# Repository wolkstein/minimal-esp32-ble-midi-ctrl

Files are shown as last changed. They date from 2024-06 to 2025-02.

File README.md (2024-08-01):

# Minimal ESP32 BLE Midi Control Interface

This project is a minimal ESP32 BLE MIDI controller. It allows you to control MIDI devices wirelessly using Bluetooth Low Energy (BLE) technology. The controller is designed to be compact and easy to use, making it ideal for musicians and performers.

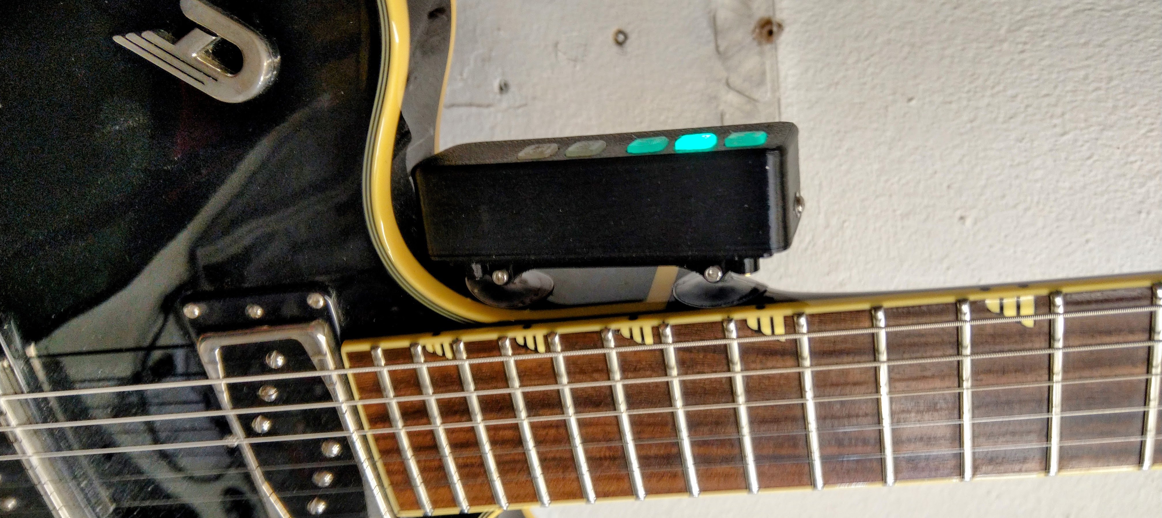
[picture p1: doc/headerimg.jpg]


## Features

- BLE MIDI connectivity
- Compact and portable design
- Easy-to-use interface
- Easy-to-use Web UI to make settings
- Online Firmware Update
- With Ardour and Harrison Mixbus compatible midi_map file
- as Platformio Project (esp32 arduino framework)

## Parts
- ESP32-S3-Mini
- 5 momentary button switches
- 5 10k resistors
- breadboard
- optional rgb led ws28xx

## PCB Version with Lipo and Battery Charger

PCB:

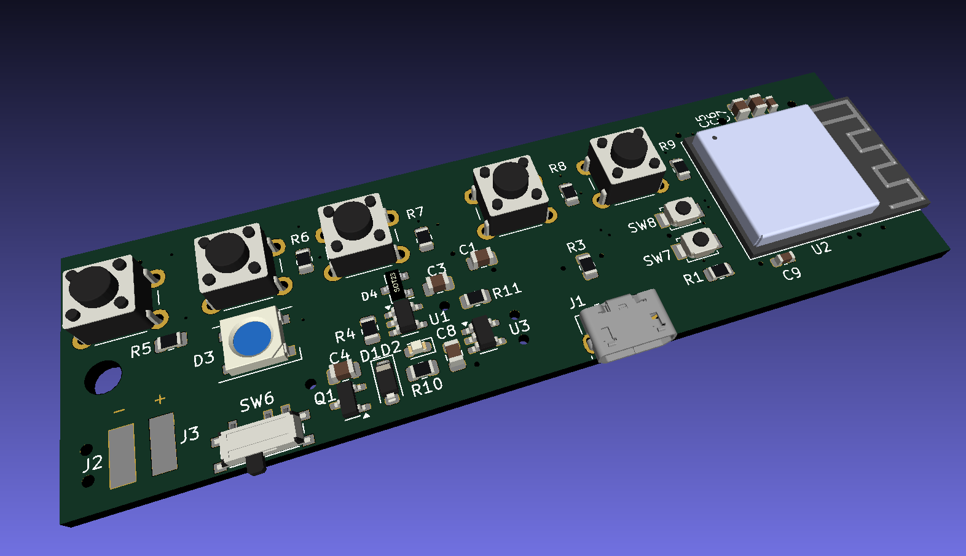
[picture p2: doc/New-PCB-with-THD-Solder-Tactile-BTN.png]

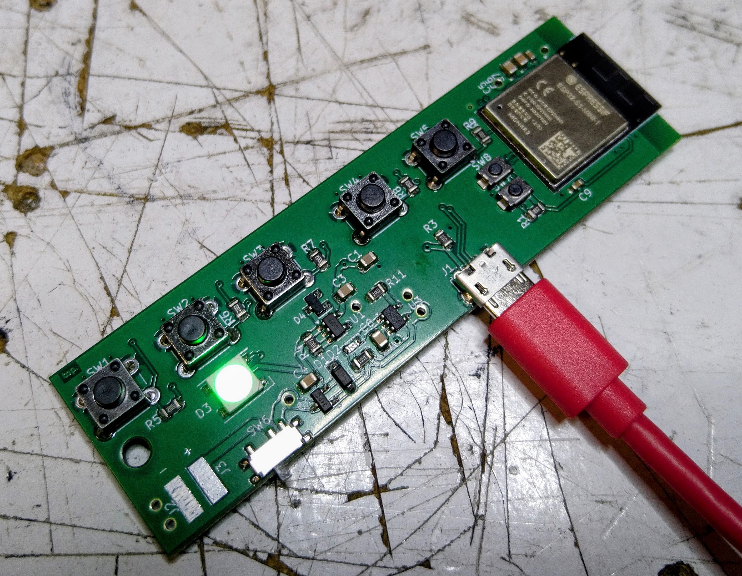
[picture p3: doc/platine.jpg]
PCB - finished


Housing:
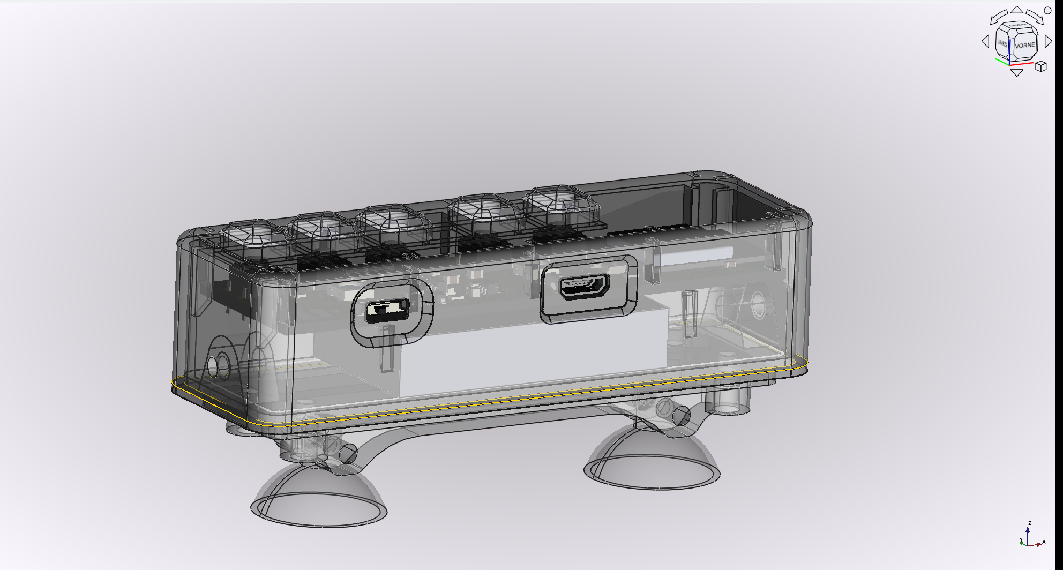
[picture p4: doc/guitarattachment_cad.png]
Housing


## Getting Started

To get started with the project, follow these steps:

1. Clone the repository: `$ git clone https://github.com/wolkstein/minimal-esp32-ble-midi-ctrl`
2. Open as Platformio Project for example with VSC Pio Extension
3. Connect your ESP32 device to your computer via USB.
4. Change the platformio.ini as you need
5. Press PIO upload button
6. Your ESP32 BLE MIDI controller is now ready to use!

## Contributing

Contributions are welcome! If you have any ideas, suggestions, or bug reports, please open an issue or submit a pull request.

## License

This project is licensed under the GNU General Public License v3.0. See the [LICENSE](LICENSE) file for more information.

## Linux howto BlueZ with MIDI over BLE Support

Nice Howto from Peter P:

https://tttapa.github.io/Pages/Ubuntu/Software-Installation/BlueZ.html

After compiling BlueZ, Little Helper shown in Catja App

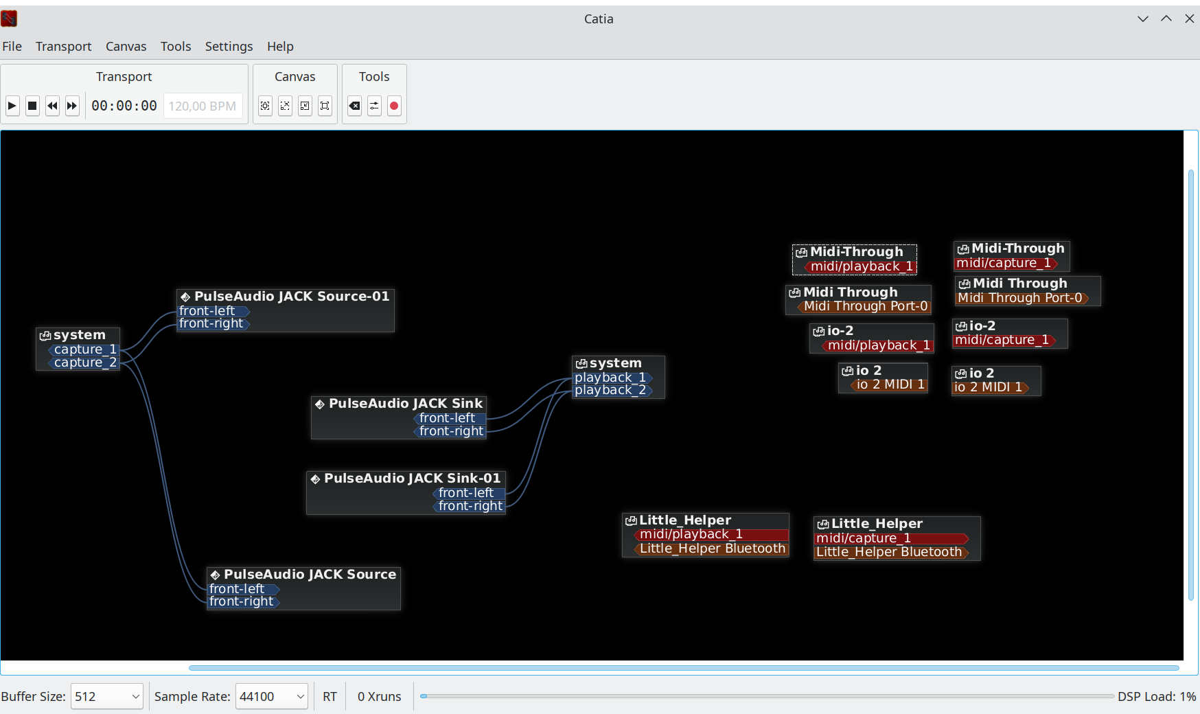
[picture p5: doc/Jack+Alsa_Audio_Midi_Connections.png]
Catja on Ubuntu 22.04


## Ardour / Mixbus Midi Setup

- For example copy the Midi Map file from this Repo like this:
```bash
cp DAW_MIDI_MAPS/ArdourAndHarrisonMixbus/midi_mapsLittle_Helper.map ~/.config/ardour6/midi_maps
```
- Now you can open the Edit-Preferences Window in Ardour, and under Control Surfaces, select Generic Midi
- Press Show Protocol Settings
- Now you can select "Little_Helper" in Midi Bindings dropdown
- if Little Helper is already connected via bluetooth you can make connection in Incoming Midi Dropdown like in the Image below
- Done  

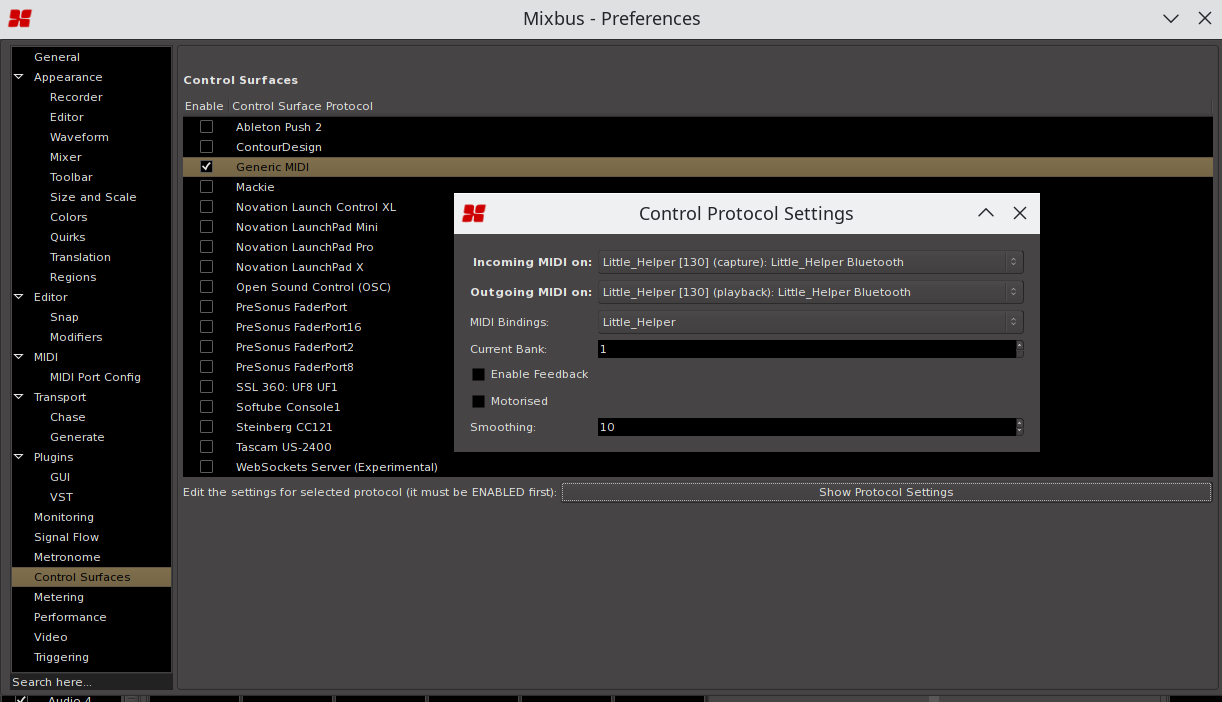
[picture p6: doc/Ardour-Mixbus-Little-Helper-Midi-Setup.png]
Ardour Mixbus Midi


---
## Some more pictures of how it is used

### All parts

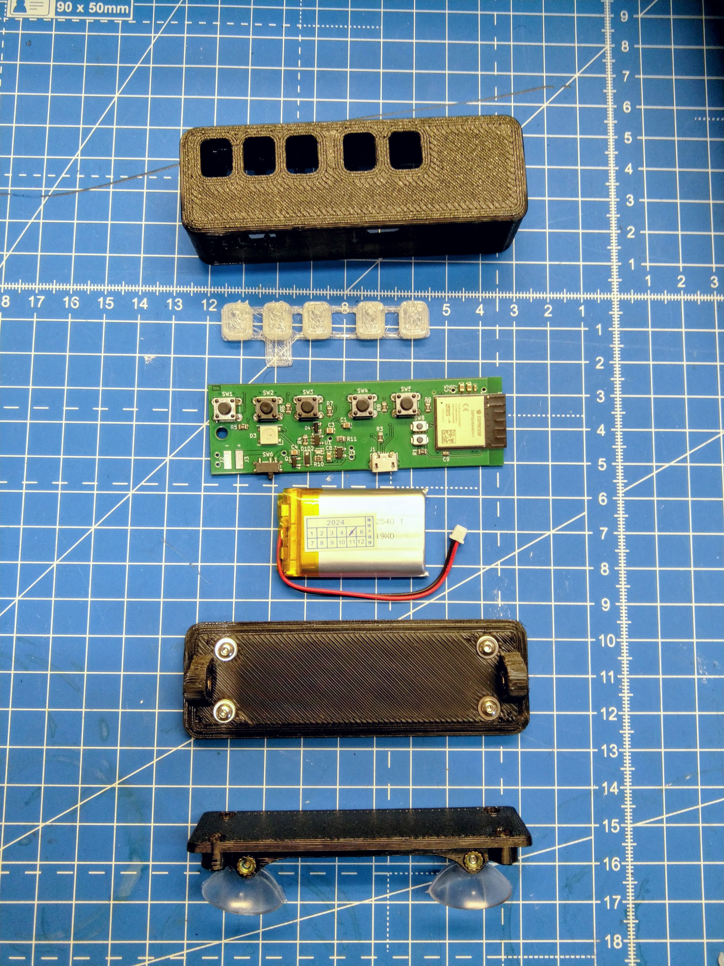
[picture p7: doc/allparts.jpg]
All Parts


### Guitar attachment

Guitar attachment cad
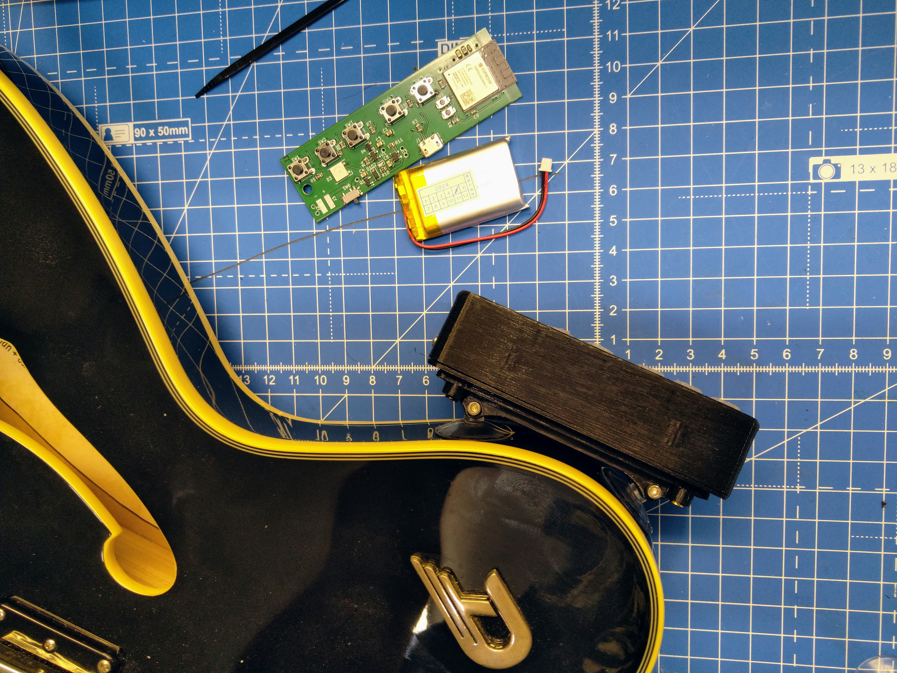
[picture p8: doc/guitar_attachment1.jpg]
Guitar attachment

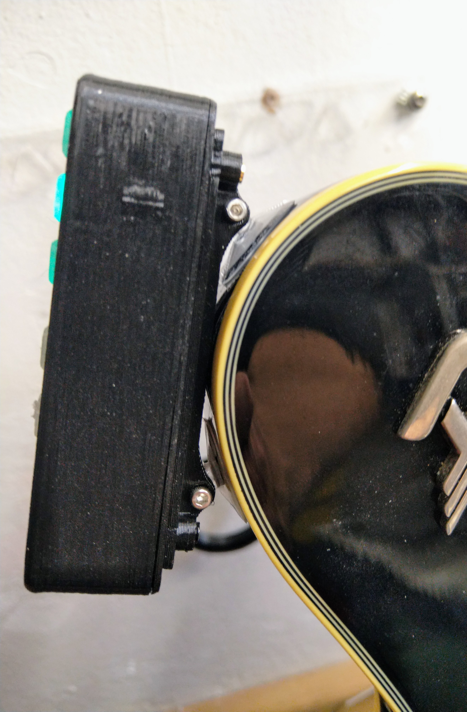
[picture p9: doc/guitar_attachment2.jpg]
Guitar attachment

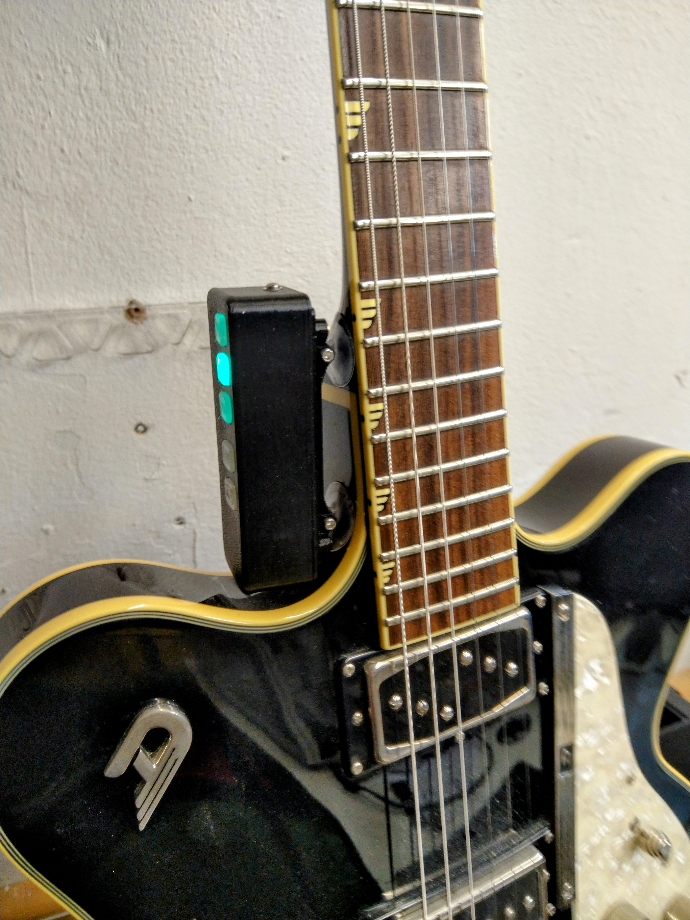
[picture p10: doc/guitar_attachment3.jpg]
Guitar attachment


### Web interface

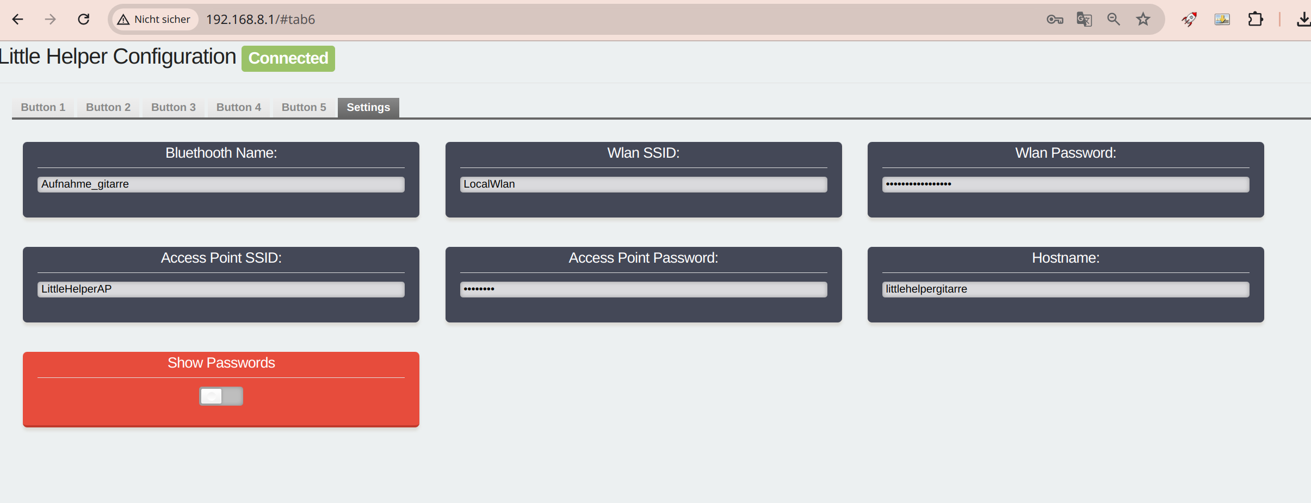
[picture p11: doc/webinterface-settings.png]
Settings

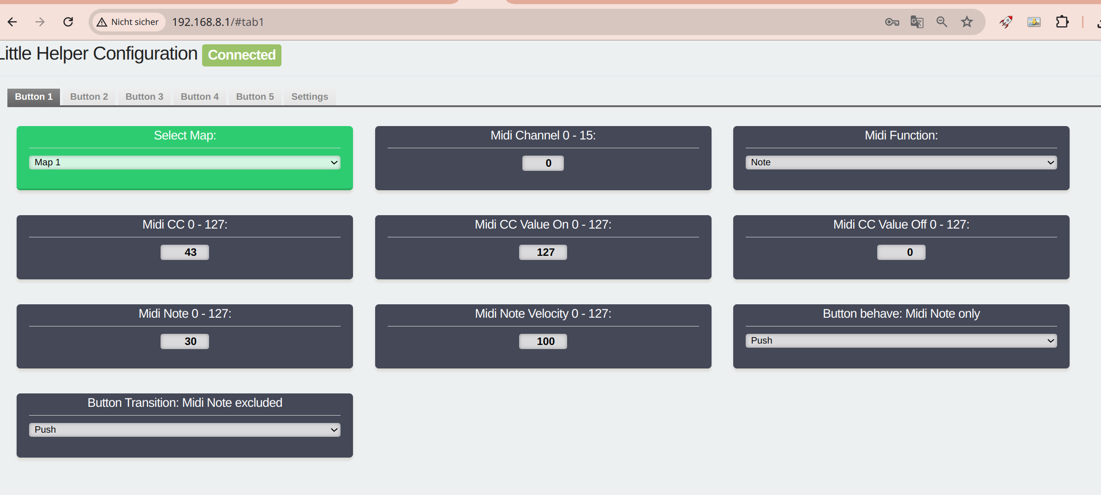
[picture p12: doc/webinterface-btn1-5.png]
Btn Tabs 1 - 5


---
## Simple Manual

### First Wi-Fi Connection and Settings

#### To connect to the built-in access point, follow these steps:

1. Power on your ESP32 BLE MIDI controller while pressing Btn 4 and 5
2. Wait til LED becomes Blue
3. Once initialized, the controller will start broadcasting its own access point (AP) named "LittleHelperAP-xxx"
4. On your computer or mobile device, go to the Wi-Fi settings and connect to the "LittleHelperAP-xxx" network.
5. Open a web browser and enter the following URL: `http://192.168.8.1`.
6. You will be redirected to the controller's web interface.
7. In the web interface, navigate to the "Settings" Tab.

After completing the initial steps, the device is now capable of connecting to a local network. If the user desires, they can hold down buttons 4 and 5 while powering down the device. This will allow the device to connect to a local Wi-Fi network and start the web UI for making MIDI settings, if necessary.

## Firmware Update over WiFi Connection

To update the firmware of your ESP32 BLE MIDI controller over a WiFi connection, follow these steps:

1. Ensure that your ESP32 BLE MIDI controller is connected to your local WiFi network. You can do this by navigating to the "Settings" tab in the controller's web interface and entering your WiFi credentials.

2. Once connected, go to the Settings Tab and check the label that displays the current firmware version (e.g., s3miniVx).

3. Visit the GitHub project page for Little Helper and go to the "Binary" folder (https://github.com/wolkstein/minimal-esp32-ble-midi-ctrl/tree/main/bin) to check if there is a newer firmware available. Look for a firmware version number that is higher than the one displayed in the firmware label.

4. If a newer firmware is available, you can proceed with the update.

5. In the Settings Tab, click the "Try Update" button to request the firmware update.

6. After clicking the button, you will see a message saying "Update Requested, need Reboot".

7. Turn off the power to your ESP32 BLE MIDI controller by switching the power switch to the "off" position and removing the USB cable.

8. Power on the device again either by switching the power switch back on or by connecting the USB cable.

9. Wait for the LED on the device to turn yellow. This indicates that the device is in update mode and is connected to your local network.

10. If the LED starts blinking purple, it means that the update process is running. Wait until the LED switches back to its normal red or green light. If the LED does not blink purple, it means that the device has rebooted without performing the update.

11. If the update fails, you can simply try again. If something goes wrong during the update, the previous firmware will be automatically recovered.

12. If the update is successful, you can reconnect to the web interface and check the firmware version label to confirm the update.

---
# Button Combinations at Power up

This section describes the button combinations and their corresponding functions that can be used during power up.
Btn 1 to btn 5 from left to right.

| Button Combination | Function |
| --- | --- |
| o o o x x | Connect To Local Wifi Network and enable Web UI |
| o o x x x | Start AP Mode and enable Web UI |
| x x o o o | Reset Midi Settings to Default |
| x o x o o | Reset Midi Settings and Wifi Settings to Default |

x = pressed,
o = released

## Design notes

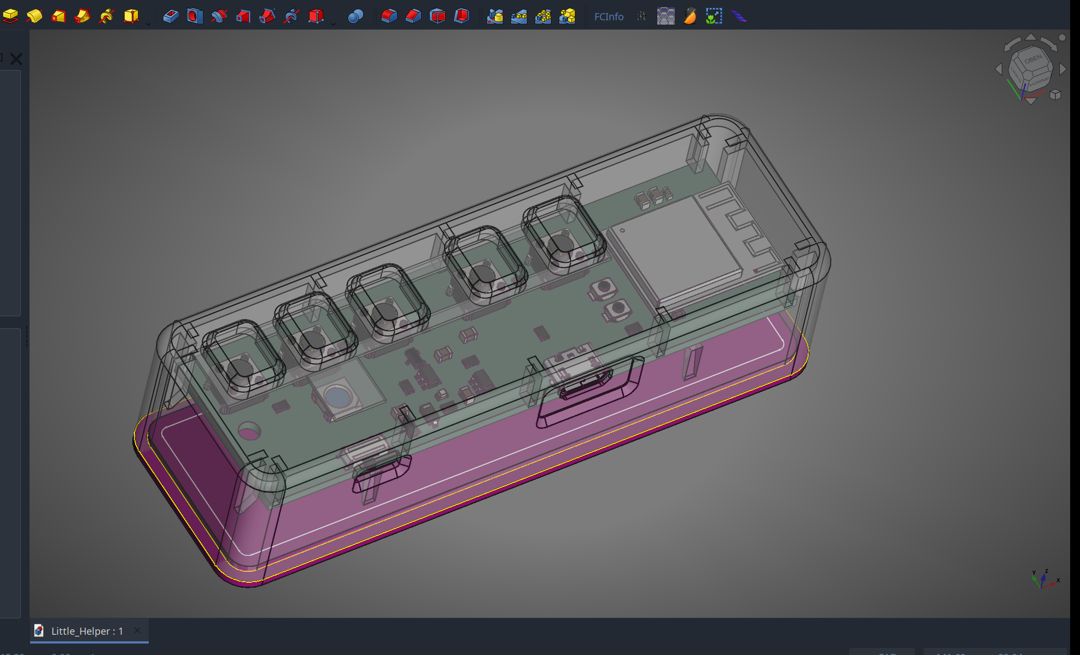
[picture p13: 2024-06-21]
doc/Freecad-Housing.png

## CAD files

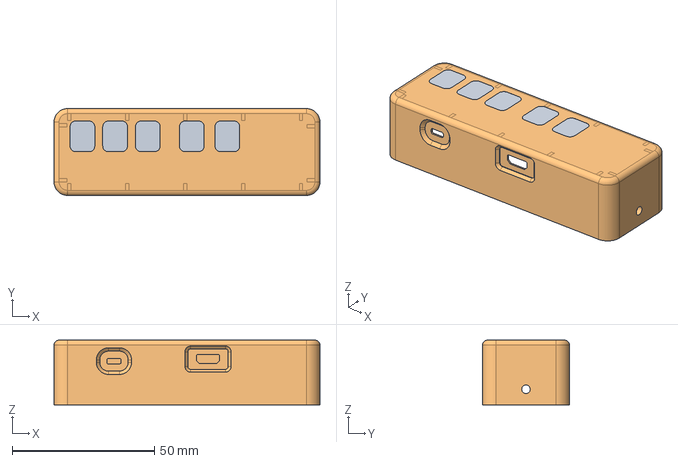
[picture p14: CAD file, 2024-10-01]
Hardware/FreeCadProject/Little_Helper.FCStd
93.6 x 30.6 x 22.8 mm
Housing

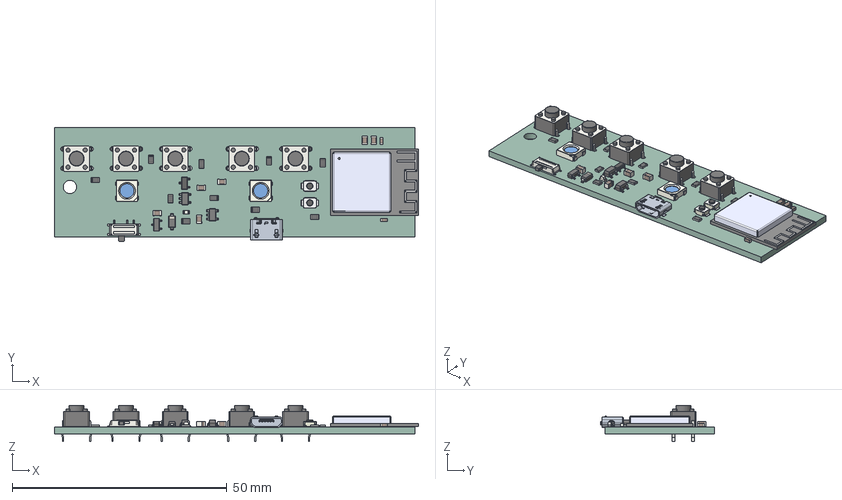
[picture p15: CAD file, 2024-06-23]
Hardware/KicadProject/Little_Helper/Little_Helper.step
84.8 x 26.7 x 8.50 mm
ESP32-S3-MINI-1-N8
LED_0603_1608Metric
R_0805_2012Metric x 10
C_0805_2012Metric x 6
SW_SPST_B3U-1000P x 2
SW_PUSH_6mm_h5mm x 5
C_0603_1608Metric x 2
LED_WS2812B_PLCC4_50x50mm_P32mm x 2
SOT_23
Pad_(Mirror_#2)
Fusion_sp
SOT_23_5 x 2
D_SOD_123
Little_Helper_PCB

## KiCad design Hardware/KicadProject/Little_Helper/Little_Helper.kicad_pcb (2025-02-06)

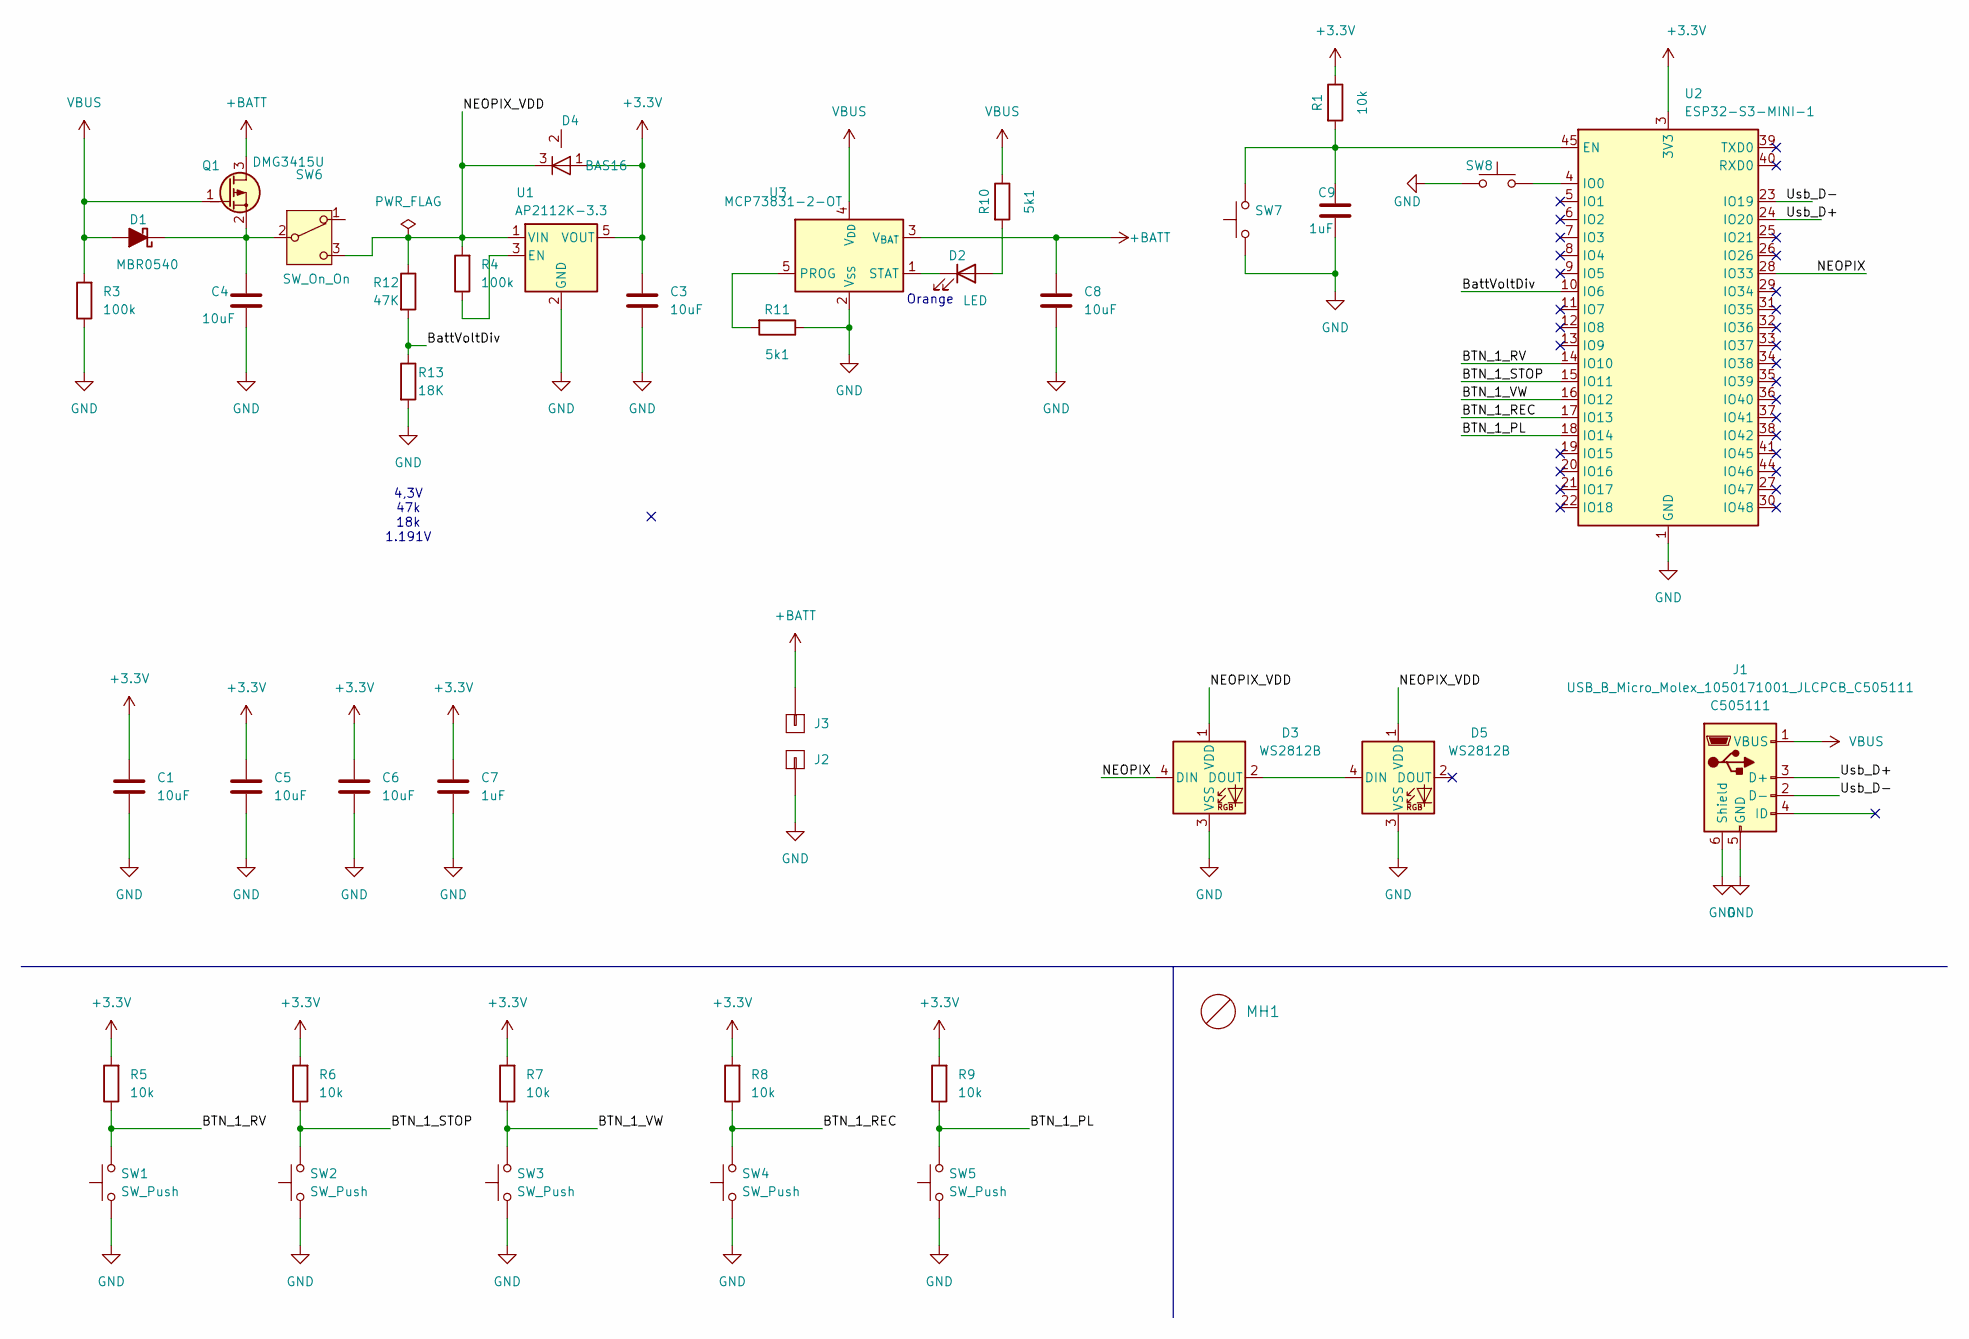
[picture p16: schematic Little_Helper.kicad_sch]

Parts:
C1, C3, C4, C5, C6, C8: 10uF; C_0805_2012Metric; LCSC C1713
C7, C9: 1uF; C_0603_1608Metric; LCSC C1592
D1: MBR0540; D_SOD-123; LCSC C78545
D2: LED; LED_0603_1608Metric; LCSC C2286
D3, D5: WS2812B; LED_WS2812B_JLCPCB_5.0x5.0mm_P3.2mm; LCSC C2843785
D4: BAS16; sot_23; MPN BAS16,215; LCSC C79997
J1: USB_B_Micro_Molex_1050171001_JLCPCB_C505111; USB_Micro-B_Molex-105017-0001; MPN 1050171001; LCSC Part # C505111
J2, J3: SOLDER_CON_5x2_TOP; solder_con_5x2_top
MH1: fit_3_1
Q1: DMG3415U; SOT-23; LCSC C96616
R1, R5, R6, R7, R8, R9: 10k; R_0805_2012Metric; LCSC C17414
R3, R4: 100k; R_0805_2012Metric; LCSC C149504
R10, R11: 5k1; R_0805_2012Metric; LCSC C115316
R12: 47K; r2012; LCSC Part # C17713
R13: 18K; r2012; LCSC Part # C17506
SW1, SW2, SW3, SW4, SW5: SW_Push; SW_PUSH_6mm_H5mm
SW6: SW_On_On; SW_SPDT_PCM12; MPN MK-12C02-G020; LCSC Part # C963206
SW7, SW8: SW_Tactile_Small; SW_SPST_TS-1088-AR02016; MPN TS-1088-AR02016; LCSC Part # C720477
U1: AP2112K-3.3; SOT-23-5; LCSC C51118
U2: ESP32-S3-MINI-1; ESP32-S2-MINI-1; LCSC C2913206
U3: MCP73831-2-OT; SOT-23-5; LCSC C424093

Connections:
+3.3V: C1.1, C3.1, C5.1, C6.1, C7.1, D4.1 (A), R1.1, R5.2, R6.2, R7.2, R8.2, R9.2, U1.5 (VOUT), U2.3 (3V3)
+BATT: C8.1, J3.1, Q1.3 (D), U3.3 (V_{BAT})
/BTN_1_PL: R9.1, SW5.2, U2.18 (IO14)
/BTN_1_REC: R8.1, SW4.2, U2.17 (IO13)
/BTN_1_RV: R5.1, SW1.2, U2.14 (IO10)
/BTN_1_STOP: R6.1, SW2.2, U2.15 (IO11)
/BTN_1_VW: R7.1, SW3.2, U2.16 (IO12)
/BattVoltDiv: R12.2, R13.1, U2.10 (IO6)
/NEOPIX: D3.4 (DIN), U2.28 (IO33)
/NEOPIX_VDD: D3.1 (VDD), D4.3 (K), D5.1 (VDD), R4.2, R12.1, SW6.3 (C), U1.1 (VIN)
/Usb_D+: J1.3 (D+), U2.24 (IO20)
/Usb_D-: J1.2 (D-), U2.23 (IO19)
GND: C1.2, C3.2, C4.2, C5.2, C6.2, C7.2, C8.2, C9.2, D3.3 (VSS), D5.3 (VSS), J1.5 (GND), J1.6 (Shield), J2.1, R3.1, R11.1, R13.2, SW1.1, SW2.1, SW3.1, SW4.1, SW5.1, SW7.1 (A), SW8.1 (A), U1.2 (GND), U2.1 (GND), U2.2 (GND), U2.42 (GND), U2.43 (GND), U2.46 (GND), U2.47 (GND), U2.48 (GND), U2.49 (GND), U2.50 (GND), U2.51 (GND), U2.52 (GND), U2.53 (GND), U2.54 (GND), U2.55 (GND), U2.56 (GND), U2.57 (GND), U2.58 (GND), U2.59 (GND), U2.60 (GND), U2.61 (GND), U2.62 (GND), U2.63 (GND), U2.64 (GND), U2.65 (GND), U3.2 (V_{SS})
unnamed: C4.1, D1.1 (K), Q1.2 (S), SW6.2 (B)
unnamed: D2.2 (A), R10.2
unnamed: D2.1 (K), U3.1 (STAT)
unnamed: D3.2 (DOUT), D5.4 (DIN)
unnamed: R4.1, U1.3 (EN)
unnamed: C9.1, R1.2, SW7.2 (A), U2.45 (EN)
unnamed: SW8.2 (A), U2.4 (IO0)
unnamed: R11.2, U3.5 (PROG)
VBUS: D1.2 (A), J1.1 (VBUS), Q1.1 (G), R3.2, R10.1, U3.4 (V_{DD})

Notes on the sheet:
4,3V 47k 18k 1.191V
Orange

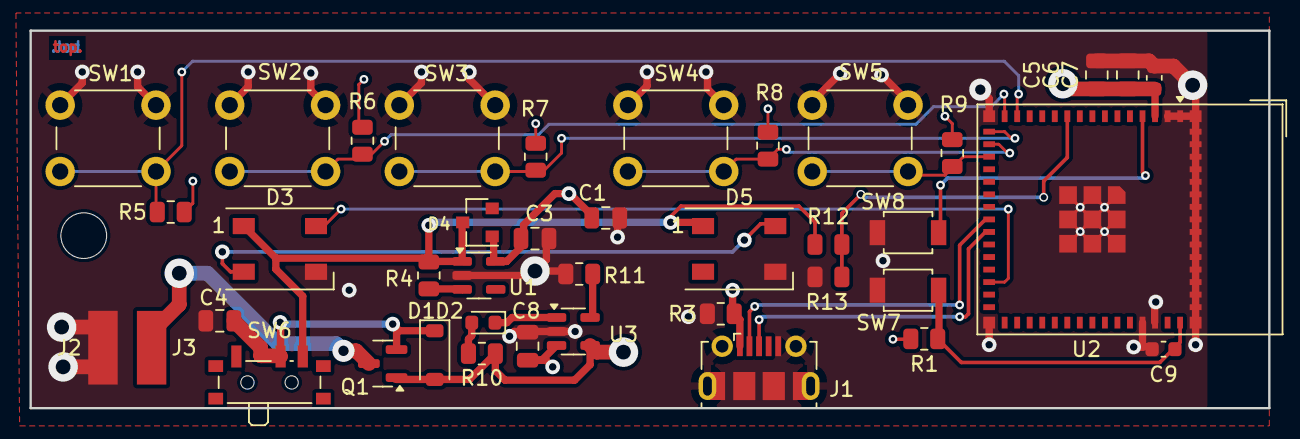
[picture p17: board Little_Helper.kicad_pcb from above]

Board: 4 copper layers, 84.0 x 25.6 mm, 41 parts (0 on the bottom side), 22 nets.

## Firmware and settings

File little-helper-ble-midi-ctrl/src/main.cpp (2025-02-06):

/**
 * @file main.cpp
 * @brief This file contains the main code for the Little Helper BLE MIDI Controller.
 * @author Michael Wolkstein (wolke@k-27.de)
 * @version 1.0
 * @date 2024-07-07
 * 
 * @details The Little Helper BLE MIDI Controller is a device that allows you to control MIDI devices wirelessly using Bluetooth Low Energy (BLE) technology. It uses an ESP32 microcontroller and various libraries such as Arduino, BLEMidi, FastLED, and AceButton.
 * 
 * The code initializes the necessary libraries, defines constants for the WiFi network, button configurations, and LED settings. It also includes callback functions for the web UI and button events.
 * 
 * The main functionality of the code is to handle button events, such as button presses and long presses. It retrieves the button configuration based on the GPIO pin and the active map. It then performs the corresponding actions, such as sending MIDI messages or updating the button state.
 * 
 * The code also includes functions for saving and loading button settings from the preferences, as well as web UI callbacks for selecting button mappings and MIDI functions.
 * 
 * This code is licensed under the GNU General Public License version 3 (GPL-3.0).
 */

#define USE_OTA
#include "main.h"
#include <Arduino.h>
#include <BLEMidi.h>
#include <FastLED.h>
#include <AceButton.h>
#include <Preferences.h>
//#include "esp32-hal-log.h"
#include "esp_log.h"

#include <DNSServer.h>
#include <ESPUI.h>

#include <WiFi.h>

// // ota network requirements
#ifdef USE_OTA
  #include <HTTPClient.h>
  #include <WiFiClientSecure.h>
  #include <Update.h>
#endif


const byte DNS_PORT = 53;
IPAddress apIP(192, 168, 8, 1);
DNSServer dnsServer;


// // OTA Update globals
// // Constants for server details
#ifdef USE_OTA
  const char* SERVER = "https://raw.githubusercontent.com"; // Your server address
  const int SERVER_PORT = 443; // Typically 443 for HTTPS
  const char* PATH = "/wolkstein/minimal-esp32-ble-midi-ctrl/main/bin/s3miniV"; // Path to the firmware
  bool __ota_update_running = false;
#endif



unsigned int __FW_VERSION = 8; // Firmware Version only Major Versions number
bool __DO_UPDATE = false;
bool __UPDATE_FAILURE = false;
int __UPDATE_ERROR_CODE = -1;

Preferences prefs;

using namespace ace_button;

// LED Strucutre
CRGB myWS28XXLED[NUM_LEDS];

CRGB __oldLedColor;

uint8_t __numBlincs = 1;
uint32_t __oldNumBlinktime = 0;
uint32_t __oldBlinktime = 0;

// Button Structure now with n Maps, first we try 4 Maps
myButton myBtnMap[5] = { // 5 Buttons 4 Maps Map 1 und Map 2 are short press values, Map 3 and Map 4 are long press values
  { // Button 1
     10,  // GPIO Pin
     {false, false, false, false}, // Button Release
     {BTN_PUSH, BTN_PUSH, BTN_PUSH, BTN_PUSH},// Button Function 0 = Push, 1 = Toggle
     {false, false, false, false}, // Button Long Press
     {BTN_OFF, BTN_OFF, BTN_OFF, BTN_OFF}, // Button State 0 = Off, 1 = On
     {CRGB::Red, CRGB::Red, CRGB::Red, CRGB::Red}, // Button Color 0 = Red, 1 = Green, 2 = Blue, 3 = Yellow, 4 = Purple, 5 = Cyan, 6 = White
     {MIDIFUNC_CC, MIDIFUNC_CC, MIDIFUNC_CC, MIDIFUNC_CC}, // Button MIDI Function 0 = Note, 1 = CC, 2 = MMC, 3 = Program Change
     {MIDI_CH_1, MIDI_CH_1, MIDI_CH_1, MIDI_CH_1}, // Button MIDI Channel 0 - 15
     {60, 60, 60, 60}, // Button MIDI Note 0 - 127
     {100, 100,100, 100}, // Button MIDI Velocity 0 - 127
     {43, 111, 43, 111}, // Button MIDI CC 0 - 127
     {127, 127, 127, 127}, // Button MIDI CC ON Value 0 - 127
     {0, 0, 0, 0}, // Button MIDI CC OFF Value 0 - 127
     {MMC_REWIND, MMC_REWIND, MMC_REWIND, MMC_REWIND} // Button MIDI MMC 0 - 13
  },
  { // Button 2
     11,  // GPIO Pin
     {false, false, false, false}, // Button Release
     {BTN_PUSH, BTN_PUSH, BTN_PUSH, BTN_PUSH},// Button Function 0 = Push, 1 = Toggle
     {false, false, false, false}, // Button Long Press
     {BTN_OFF, BTN_OFF, BTN_OFF, BTN_OFF}, // Button State 0 = Off, 1 = On
     {CRGB::Yellow, CRGB::Yellow, CRGB::Yellow, CRGB::Yellow}, // Button Color 0 = Red, 1 = Green, 2 = Blue, 3 = Yellow, 4 = Purple, 5 = Cyan, 6 = White
     {MIDIFUNC_CC, MIDIFUNC_CC, MIDIFUNC_CC, MIDIFUNC_CC}, // Button MIDI Function 0 = Note, 1 = CC, 2 = MMC, 3 = Program Change
     {MIDI_CH_1, MIDI_CH_1, MIDI_CH_1, MIDI_CH_1}, // Button MIDI Channel 0 - 15
     {61, 61, 61, 61}, // Button MIDI Note 0 - 127
     {100, 100, 100, 100}, // Button MIDI Velocity 0 - 127
     {42, 42, 42, 42}, // Button MIDI CC 0 - 127
     {127, 127, 127, 127}, // Button MIDI CC ON Value 0 - 127
     {0, 0, 0, 0}, // Button MIDI CC OFF Value 0 - 127
     {MMC_STOP, MMC_STOP, MMC_STOP, MMC_STOP} // Button MIDI MMC 0 - 13
  },
  { // Button 3
     12,  // GPIO Pin
     {false, false, false, false}, // Button Release
     {BTN_PUSH, BTN_PUSH, BTN_PUSH, BTN_PUSH},// Button Function 0 = Push, 1 = Toggle
     {false, false, false, false}, // Button Long Press
     {BTN_OFF, BTN_OFF, BTN_OFF, BTN_OFF}, // Button State 0 = Off, 1 = On
     {CRGB::Cyan, CRGB::Cyan, CRGB::Cyan, CRGB::Cyan}, // Button Color 0 = Red, 1 = Green, 2 = Blue, 3 = Yellow, 4 = Purple, 5 = Cyan, 6 = White
     {MIDIFUNC_CC, MIDIFUNC_CC, MIDIFUNC_CC, MIDIFUNC_CC}, // Button MIDI Function 0 = Note, 1 = CC, 2 = MMC, 3 = Program Change
     {MIDI_CH_1, MIDI_CH_1, MIDI_CH_1, MIDI_CH_1}, // Button MIDI Channel 0 - 15
     {62, 62, 62, 62}, // Button MIDI Note 0 - 127
     {100, 100, 100, 100}, // Button MIDI Velocity 0 - 127
     {44, 112, 44, 112}, // Button MIDI CC 0 - 127
     {127, 127, 127, 127}, // Button MIDI CC ON Value 0 - 127
     {0, 0, 0, 0}, // Button MIDI CC OFF Value 0 - 127
     {MMC_STOP, MMC_STOP, MMC_STOP, MMC_STOP} // Button MIDI MMC 0 - 13
  },
  { // Button 4
     13,  // GPIO Pin
     {true, true, true, true}, // Button Release
     {BTN_PUSH, BTN_PUSH, BTN_PUSH, BTN_PUSH},// Button Function 0 = Push, 1 = Toggle
     {false, true, false, true}, // Button Long Press
     {BTN_OFF, BTN_OFF, BTN_OFF, BTN_OFF}, // Button State 0 = Off, 1 = On
     {CRGB::Aquamarine, CRGB::Aquamarine, CRGB::Aquamarine, CRGB::Aquamarine}, // Button Color 0 = Red, 1 = Green, 2 = Blue, 3 = Yellow, 4 = Purple, 5 = Cyan, 6 = White
     {MIDIFUNC_CC, MIDIFUNC_CC, MIDIFUNC_CC, MIDIFUNC_CC}, // Button MIDI Function 0 = Note, 1 = CC, 2 = MMC, 3 = Program Change
     {MIDI_CH_1, MIDI_CH_1, MIDI_CH_1, MIDI_CH_1}, // Button MIDI Channel 0 - 15
     {62, 62, 62, 62}, // Button MIDI Note 0 - 127
     {100, 100, 100, 100}, // Button MIDI Velocity 0 - 127
     {45, 64, 45, 64}, // Button MIDI CC 0 - 127
     {127, 127, 127, 127}, // Button MIDI CC ON Value 0 - 127
     {0, 0, 0, 0}, // Button MIDI CC OFF Value 0 - 127
     {MMC_STOP, MMC_STOP, MMC_STOP, MMC_STOP} // Button MIDI MMC 0 - 13
  },
  { // Button 5
     14,  // GPIO Pin
     {false, false, false, false}, // Button Release
     {BTN_PUSH, BTN_PUSH, BTN_PUSH, BTN_PUSH},// Button Function 0 = Push, 1 = Toggle
     {false, false, false, false}, // Button Long Press
     {BTN_OFF, BTN_OFF, BTN_OFF, BTN_OFF}, // Button State 0 = Off, 1 = On
     {CRGB::Blue, CRGB::Blue, CRGB::Blue, CRGB::Blue}, // Button Color 0 = Red, 1 = Green, 2 = Blue, 3 = Yellow, 4 = Purple, 5 = Cyan, 6 = White
     {MIDIFUNC_CC, MIDIFUNC_CC, MIDIFUNC_CC, MIDIFUNC_CC}, // Button MIDI Function 0 = Note, 1 = CC, 2 = MMC, 3 = Program Change
     {MIDI_CH_1, MIDI_CH_1, MIDI_CH_1, MIDI_CH_1}, // Button MIDI Channel 0 - 15
     {62, 62, 62, 62}, // Button MIDI Note 0 - 127
     {100, 100, 100, 100}, // Button MIDI Velocity 0 - 127
     {41, 41, 41, 41}, // Button MIDI CC 0 - 127
     {127, 127, 127, 127}, // Button MIDI CC ON Value 0 - 127
     {0, 0, 0, 0}, // Button MIDI CC OFF Value 0 - 127
     {MMC_STOP, MMC_STOP, MMC_STOP, MMC_STOP} // Button MIDI MMC 0 - 13
  },
};


AceButton btn1(myBtnMap[0].btnGpio); // GPIO 10
AceButton btn2(myBtnMap[1].btnGpio); // GPIO 11
AceButton btn3(myBtnMap[2].btnGpio); // GPIO 12
AceButton btn4(myBtnMap[3].btnGpio); // GPIO 13
AceButton btn5(myBtnMap[4].btnGpio); // GPIO 14

myButton* getMyButton(int pin) {
    switch(pin) {
        case 10: return &myBtnMap[0];
        case 11: return &myBtnMap[1];
        case 12: return &myBtnMap[2];
        case 13: return &myBtnMap[3];
        case 14: return &myBtnMap[4];
        default: return nullptr; // oder einen gültigen Standardwert zurückgeben
    }
}

#ifdef USE_OTA

void otaUpdate(Control* sender, int type) {
  // set an boot variable into nvs to check next time boot.
  prefs.begin("doupdate");  //Open namespace Settings
  prefs.putBool("doupdate", true);
  prefs.end(); // close the Settings Namespace

  ESPUI.updateControlValue(sender, "Update requested need Reeboot");
}

void justotaUpdate() {

  // reset firmware update flag
  prefs.begin("doupdate");  //Open namespace Settings
  prefs.putBool("doupdate", false);
  prefs.end(); // close the Settings Namespace

  __UPDATE_FAILURE = true; // set this true, while this function is running
  prefs.begin("updatefail");  //Open namespace Settings
  prefs.putBool("updatefail", __UPDATE_FAILURE);
  prefs.end(); // close the Settings Namespace

  if (__ota_update_running) {
    Serial.println("OTA update already running.");
    return;
  }
  
  __ota_update_running = true;
  WiFiClientSecure wifiClientSSL;
  wifiClientSSL.setInsecure(); // Not recommended for production, better to handle certificates properly

  HTTPClient https;
  char updateURL[100];
  snprintf(updateURL, sizeof(updateURL), "%s%s%d.bin", SERVER, PATH, __FW_VERSION + 1);

  Serial.print("Checking for update file: ");
  Serial.println(updateURL);

  https.begin(wifiClientSSL, updateURL); // Begin connection

  int httpCode = https.GET(); // Make the GET request

  Serial.print("Update status code: ");
  Serial.println(httpCode);

  if (httpCode != HTTP_CODE_OK) {
    Serial.println("Failed to fetch update.");
    https.end();
    __ota_update_running = false;
    __UPDATE_ERROR_CODE = httpCode;
    prefs.begin("updateerrorcode");  //Open namespace Settings
    prefs.putInt("updateerrorcode", __UPDATE_ERROR_CODE);
    prefs.end(); // close the Settings Namespace 
    ESP.restart();
    return;
  }

  int contentLength = https.getSize();
  if (contentLength <= 0) {
    Serial.println("Invalid content length. Can't continue with update.");
    https.end();
    __ota_update_running = false;
    return;
  }

  Serial.print("Server returned update file of size ");
  Serial.print(contentLength);
  Serial.println(" bytes");

  // Prepare for the update
  Serial.print("Free heap before OTA: ");
  Serial.println(ESP.getFreeHeap());


  if (!Update.begin(contentLength, U_FLASH, 15, 0, NULL)) {
      Serial.println("Not enough space to begin OTA");
      https.end();
      __ota_update_running = false;
      return;
  } else {
      Serial.println("OTA Update started");
  }

  size_t written = 0; // Variable to store how many bytes have been written
  WiFiClient *stream = https.getStreamPtr();
  Serial.println("stream-angefordert");
  int schleifeaussen = 0;
  https.setTimeout(60000); // 12 Sekunden Timeout

  uint8_t buff[128] = { 0 }; // Größe des Buffers anpassen
  size_t len = 0; // Variable to store the length of data available for reading

  bool toggleLed = false;
  while (https.connected() && (written < contentLength)) {

      len = stream->available();
      delay(2); // Kleine Verzögerung, um dem Stream Zeit zu geben, Daten zu sammeln

      if (len > 0) {
          int c = stream->readBytes(buff, ((len < sizeof(buff)) ? len : sizeof(buff)));
          if (Update.write(buff, c) != c) {
              Serial.println("Error writing to flash. Aborting OTA.");
              Update.abort();
              return; // Verlässt die Funktion oder Schleife
          }
          

          written += c;
          //Serial.printf("len: %d, written: %d\n", len, written);
          yield(); // Ermöglicht das Ausführen von Hintergrundaufgaben, verhindert WDT-Reset
      }

      if(toggleLed) {
        myWS28XXLED[0] = CRGB::Purple;
        FastLED.show();
      } else {
        myWS28XXLED[0] = CRGB::Black;
        FastLED.show();
      }
      toggleLed = !toggleLed;
  }

  if (written == contentLength) {
      Serial.println("Written : " + String(written) + " successfully");
  }

  if (Update.end()) {
      Serial.println("OTA done!");
      if (Update.isFinished()) {
          Serial.println("Update successfully completed. Rebooting.");
          __UPDATE_FAILURE = false; // set this true, while this function is running
          prefs.begin("updatefail");  //Open namespace Settings
          prefs.putBool("updatefail", __UPDATE_FAILURE);
          prefs.end(); // close the Settings Namespace

          __UPDATE_ERROR_CODE = -1;
          prefs.begin("updateerrorcode");  //Open namespace Settings
          prefs.putInt("updateerrorcode", __UPDATE_ERROR_CODE);
          prefs.end(); // close the Settings Namespace 

          Serial.println("OTA Done!");
          Serial.printf("update fw version: %d\n", __FW_VERSION + 1);
          __FW_VERSION++;
          prefs.begin("fwversion");  //Open namespace Settings
          prefs.putUInt("fwversion", __FW_VERSION);
          prefs.end(); // close the Settings Namespace
          Serial.println("Rebooting...");
          ESP.restart();
      } else {
          Serial.println("Update not finished? Something went wrong!");
          __ota_update_running = false;
      }
  } else {
      Serial.println("Error Occurred. Error #: " + String(Update.getError()));
      __ota_update_running = false;
  }
}
#endif

// ~ OTA ~
// helper function to get the button configuration based on the GPIO pin and the active map
void saveActiveMap() {
  __numBlincs = (__active_map + 1) * 2;
    prefs.begin("active_map"); // Open NVS namespace "Settings" in RW mode
    prefs.putUInt("active_map", __active_map); // Store the active map
    prefs.end(); // Close NVS
    Serial.printf("Save Active Map: %d\n", __active_map);
    if (__active_map %2 == 0) {
      myWS28XXLED[0] = CRGB::Green;
      __oldLedColor = CRGB::Green;
    } else {
      myWS28XXLED[0] = CRGB::Purple;
      __oldLedColor = CRGB::Purple;
    }
    if(!__isConnected) myWS28XXLED[0] = CRGB::Red;
    FastLED.show();
}

// WEB UI Callbacks
void nothing(Control* sender, int type) {
    // Do nothing
}

void selectActiveMap(Control* sender, int value) {
    uint8_t active_map = static_cast<uint8_t>(String(sender->value).toInt());
    __active_map = active_map;
    __numBlincs = (__active_map + 1) * 2;
    saveActiveMap();
}

void switchShowPasswords(Control* sender, int type) {

  if(sender->value == "0") {
    ESPUI.setInputType(wlanApPasswordTxtField, "password");
    ESPUI.setInputType(wlanPasswordTxtField, "password");
  } else if(sender->value == "1") {  
    ESPUI.setInputType(wlanApPasswordTxtField, "text");
    ESPUI.setInputType(wlanPasswordTxtField, "text");
  }
}

void textCallBlueThoothName(Control* sender, int type)
{
    String value = sender->value;

    if(value.length() < 8) {
      ESPUI.updateControlValue(bleNameTxtField, "Name to short");
      return;
    }
    // Check for spaces in the string
    if (value.indexOf(' ') >= 0) {
      ESPUI.updateControlValue(bleNameTxtField, "Name contains spaces");
      return;
    }
    prefs.begin("blename", false); // Open NVS namespace "bluetooth" in RW mode
    prefs.putString("blename", value); // Store Bluetooth name
    prefs.end(); // Close NVS
    
}

void textCallSsidName(Control* sender, int type) {
    String value = sender->value;

    if(value.length() < 8) {
      ESPUI.updateControlValue(wlanSsidNameTxtField, "Name to short");
      return;
    }
    // Check for spaces in the string
    if (value.indexOf(' ') >= 0) {
      ESPUI.updateControlValue(wlanSsidNameTxtField, "Name contains spaces");
      return;
    }
    prefs.begin("wifi", false); // Open NVS namespace "wifi" in RW mode
    
    prefs.putString("ssid_local", value); // Store SSID
    
    prefs.end(); // Close NVS
    

}

void textCallWlanPassword(Control* sender, int type) {
    String value = sender->value;

    if(value.length() < 8) {
      ESPUI.updateControlValue(wlanPasswordTxtField, "Name to short");
      return;
    }
    // Check for spaces in the string
    if (value.indexOf(' ') >= 0) {
      ESPUI.updateControlValue(wlanPasswordTxtField, "Name contains spaces");
      return;
    }  
    prefs.begin("wifi", false);
    
    prefs.putString("password_local", value); // Store password
    
    prefs.end();
    

}

void textCallAPSsidName(Control* sender, int type) {
    String value = sender->value;

    if(value.length() > 16) {
      ESPUI.updateControlValue(wlanApSsidTxtField, "Name to long");
      return;
    }
    // Check for spaces in the string
    if (value.indexOf(' ') >= 0) {
      ESPUI.updateControlValue(wlanApSsidTxtField, "Name contains spaces");
      return;
    }
    prefs.begin("wifi", false); // Open NVS namespace "wifi" in RW mode
    
    prefs.putString("ssid_ap", value); // Store SSID
    
    prefs.end(); // Close NVS
    

}

void textCallAPPassword(Control* sender, int type) {
    String value = sender->value;

    if(value.length() < 8) {
      ESPUI.updateControlValue(wlanApPasswordTxtField, "Name to short");
      return;
    }
    // Check for spaces in the string
    if (value.indexOf(' ') >= 0) {
      ESPUI.updateControlValue(wlanApPasswordTxtField, "Name contains spaces");
      return;
    }
    prefs.begin("wifi", false);
    
    prefs.putString("password_ap", value); // Store password
    
    prefs.end();
    

}

void textCallHostname(Control* sender, int type) {
    String value = sender->value;

    if(value.length() < 8) {
      ESPUI.updateControlValue(hostnameTxtField, "Name to short");
      return;
    }
    // Check for spaces in the string
    if (value.indexOf(' ') >= 0) {
      ESPUI.updateControlValue(hostnameTxtField, "Name contains spaces");
      return;
    }
    WiFi.setHostname(value.c_str());
    prefs.begin("wifi", false);
    
    prefs.putString("hostname", value); // Store password
    
    prefs.end();
    
}

void textCallLedBrightness(Control* sender, int type) {


    __BRIGHTNESS = sender->value.toInt();
    FastLED.setBrightness(__BRIGHTNESS);
    FastLED.show();

    prefs.begin("wifi", false); // Open NVS namespace "wifi" in RW mode
    prefs.putUInt("LedBrightness", __BRIGHTNESS); // Store password
    
    prefs.end();
    
}

void saveSettings() {
    prefs.begin("Settings"); // Open NVS namespace "Settings" in RW mode
    
    prefs.putBytes("Settings", &myBtnMap, sizeof(myBtnMap));
    
    prefs.end();
    
}


void updateUiActiveMap(){
    char str[10];
    sprintf(str, "%d", __active_map); // Convert the number to a string
    ESPUI.updateControlValue(activeMapChooser, str); // Update the control value
}
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
void loop() {

  // Call the button service routine every loop.
  btn1.check();
  btn2.check();
  btn3.check();
  btn4.check();
  btn5.check();

  static long oldTime = 0;
  if(__configurator) {
    if (millis() - oldTime > 50){ 
        dnsServer.processNextRequest();
        oldTime = millis();
    }
  }

  if(__DO_UPDATE) justotaUpdate();

  blinkActiveMaps();
  delay(1);
}

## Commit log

2024-05-16 Add Harware Design Files(Template). Kicad Project and Freecad Project. Add MidiMaps for Ardour and HarrisonMixbus DAW.
    [Little_Helper.FCStd, Little_Helper.kicad_pcb, Little_Helper.kicad_sch]
2024-05-16 fix log_i debug info text
    [main.cpp]
2024-05-17 better longpress handling add readme.md add WS28xx rgb LED (optional)
2024-05-17 add WX2812B state Info Led
2024-05-20 After the decision was made for the ESP32-S3-Mini, the first size experiments for the case
    [Little_Helper.FCStd, Little_Helper.kicad_pcb, Little_Helper.kicad_sch]
2024-05-20 fix some library mismatch
    [Little_Helper.FCStd, Little_Helper.kicad_pcb, Little_Helper.kicad_sch]
2024-05-25 add tactile buttons
    [Little_Helper.kicad_pcb, Little_Helper.kicad_sch]
2024-06-08 board in progress
    [Little_Helper.FCStd, Little_Helper.kicad_pcb, Little_Helper.kicad_sch]
2024-06-14 some changes on pads
    [Little_Helper.kicad_pcb]
2024-06-14 change usb micro connector
    [Little_Helper.kicad_pcb, Little_Helper.kicad_sch]
2024-06-14 10uf cap from 0603 to 0805
    [Little_Helper.kicad_pcb, Little_Helper.kicad_sch]
2024-06-14 save prev changes
    [Little_Helper.kicad_pcb]
2024-06-14 add lsc parts
    [Little_Helper.kicad_sch]
2024-06-15 select the right footprint
    [Little_Helper.kicad_pcb, Little_Helper.kicad_sch]
2024-06-15 Change Putton Switch
    [Little_Helper.kicad_pcb, Little_Helper.kicad_sch]
2024-06-15 Change Boot and Reset BTN
    [Little_Helper.kicad_pcb, Little_Helper.kicad_sch]
2024-06-20 pcb layout v1.0 done
    [Little_Helper.kicad_pcb, Little_Helper.kicad_sch]
2024-06-21 First simple version of a case
    [Little_Helper-Buttons.stl, Little_Helper-Cover.stl, Little_Helper-Housing.stl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]
2024-06-21 Add Pcb Step file (CAD)
    [Little_Helper.step]
2024-06-21 Add PCB WRL file
2024-06-21 switch to board V1.1 version
    [Little_Helper.kicad_pcb, Little_Helper.kicad_sch]
2024-06-21 work on howto and housing
    [Little_Helper-Cover.stl, Little_Helper.FCStd]
2024-06-21 new Cover
    [Little_Helper-Cover.stl]
2024-06-21 add som PCB images
2024-06-23 edit pcb and footprints for pcb rev1.1
    [Little_Helper.kicad_pcb, Little_Helper.kicad_sch]
2024-06-23 restor cover
    [Little_Helper-Cover.stl, Little_Helper.FCStd]
2024-06-23 pcb v1.1 add second ws2812 led
    [Little_Helper.kicad_pcb, Little_Helper.kicad_sch]
2024-06-23 update 3d files
    [Little_Helper.step]
2024-06-24 freecad change pcb step file against wrl file
    [Little_Helper.FCStd]
2024-07-04 create little-helperesp32-s3-mini env and board file
2024-07-04 new firmware woith midi maps and AceButton Button class
2024-07-05 v1.0 on esp32-s3-mini and esp32-wroom
2024-07-05 esp32 wroom module bug
    [main.cpp]
2024-07-06 remove esp32dev target. default target is esp32-s3-mini add webui, and start to migrate configoptions for btn 1 - 5 in webui
2024-07-06 change led color function
2024-07-08 add missing main.h file and webui btn2 finished
    [main.cpp]
2024-07-08 add spi psram build flag
2024-07-09 generate Buttons for Ui more dynamicly
2024-07-10 fix pref. blename issue
    [main.cpp]
2024-07-11 UI Add Selector for Button Transition and Button behave. And the control logic
2024-07-12 add Colorhooser Button
2024-07-13 Add Guitar attachment with suction cup
    [Little_Helper-Cover.stl, Little_Helper-Housing.stl, Little_Helper-SaugnapfHalter.stl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]
2024-07-13 add some Guitar attachment images
2024-07-16 add batterie voltage divider. add colorchooser. this commit produce an major bug in button mapping. 2. Map is completly broken.
    [Little_Helper.kicad_pcb, Little_Helper.kicad_sch]
2024-07-17 fix broken mapping bug
    [main.cpp]
2024-07-25 smal modification on cad file
    [Little_Helper.FCStd]
2024-08-02 small change in housing cad. make platform fix that compiling on other linux pc's ends in a running system
    [Little_Helper-Housing.stl, Little_Helper.FCStd]
2024-10-01 Faster BLE Conect after Power
    [Little_Helper-Housing.stl, Little_Helper.FCStd]
2024-10-01 release new firmware s3miniV6.bin. faster ble conection after powering device
2025-02-06 add firmware v7 bin file
    [Little_Helper.kicad_pcb, Little_Helper.kicad_sch]
